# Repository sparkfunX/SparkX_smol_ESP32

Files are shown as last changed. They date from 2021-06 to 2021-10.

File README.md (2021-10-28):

# SparkX smôl ESP32

SparkX smôl ESP32 (SPX-18619) (https://www.sparkfun.com/products/18619)

[*SparkX smôl ESP32 (SPX-18619)*](https://www.sparkfun.com/products/18619)

The ESP32 in smôl format:
- ESP32 Processor
- WiFi antenna
- RTC crystal
- WS2812 RGB LED
- WS25Q128 128Mb Flash memory
- USB-C connector
- CP2102N USB-UART interface with RESET and BOOT control

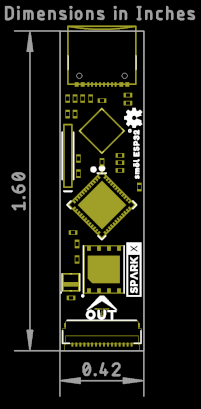
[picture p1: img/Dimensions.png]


## Repository Contents

- **/examples** - Example code for the Arduino IDE
- **/Documentation** - Datasheets etc.
- **/Hardware** - Eagle design files
- **LICENSE.md** contains the licence information

## Product Versions

- [SPX-18619](https://www.sparkfun.com/products/18619) - Original SparkX Release.

## License Information

This product is _**open source**_!

Please review the LICENSE.md file for license information.

If you have any questions or concerns on licensing, please contact technical support on our [SparkFun forums](https://forum.sparkfun.com/viewforum.php?f=123).

Distributed as-is; no warranty is given.

- Your friends at SparkFun.

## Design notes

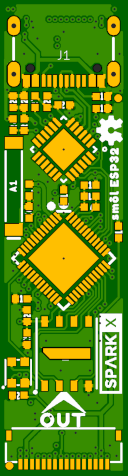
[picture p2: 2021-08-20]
img/Top.png

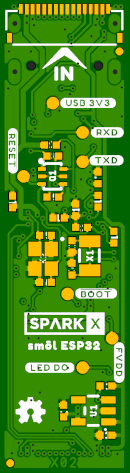
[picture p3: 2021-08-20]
img/Bottom.png

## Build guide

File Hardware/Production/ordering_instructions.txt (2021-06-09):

JLCPCB JLC7628 4-Layer 1.2mm Impedance Control
panel size, 193x96mm
PCB thickness, 1.2mm
number of layers, 4
soldermask color, Black
silkscreen color, White
oz copper, 1oz
finish, ENIG
stencils, top+bottom
pcs per panel, 32
min trace width, 0.1270mm / 0.0050in
min drill size, 0.2000mm / 0.0079in
filename to layer stackup 1/2/3/4: GTL, GL2, GL3, GBL

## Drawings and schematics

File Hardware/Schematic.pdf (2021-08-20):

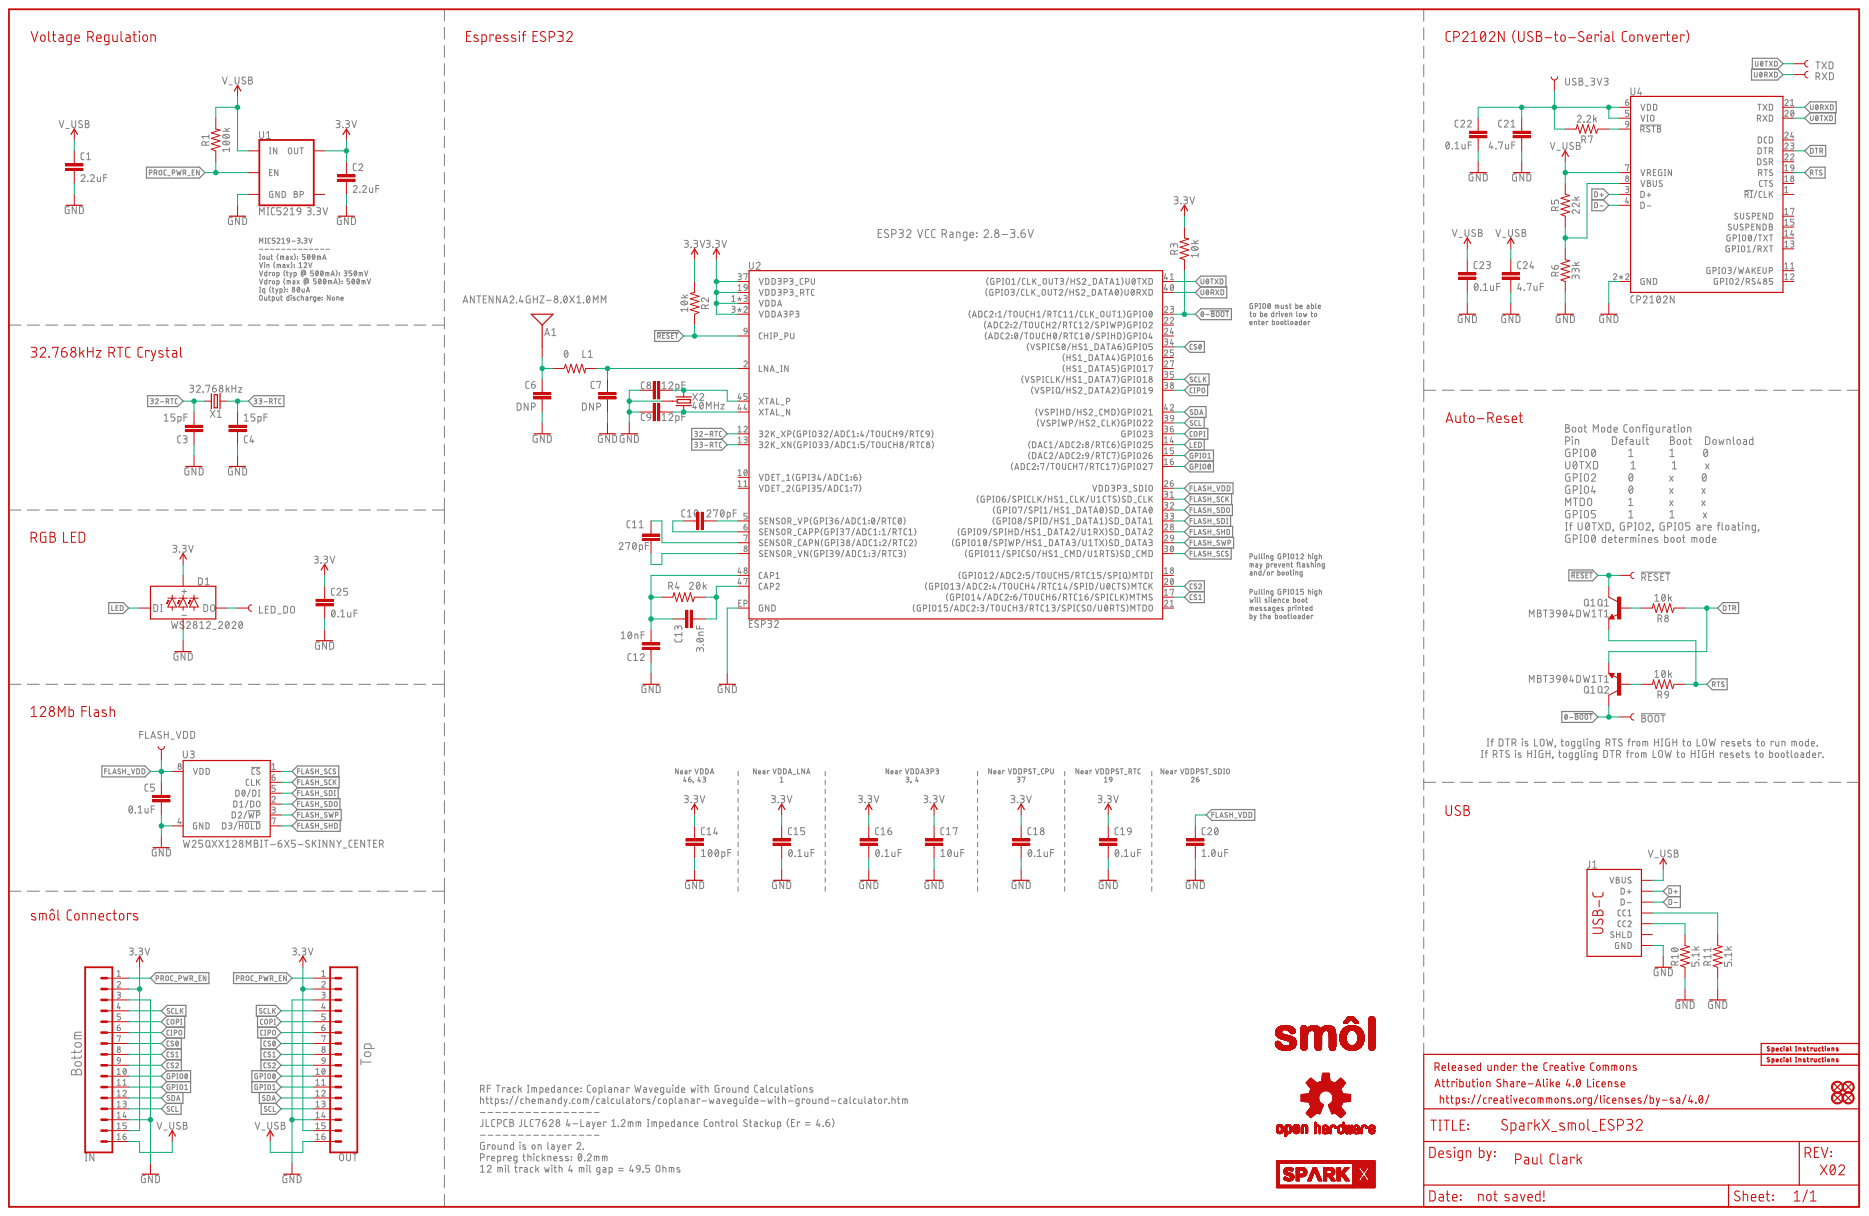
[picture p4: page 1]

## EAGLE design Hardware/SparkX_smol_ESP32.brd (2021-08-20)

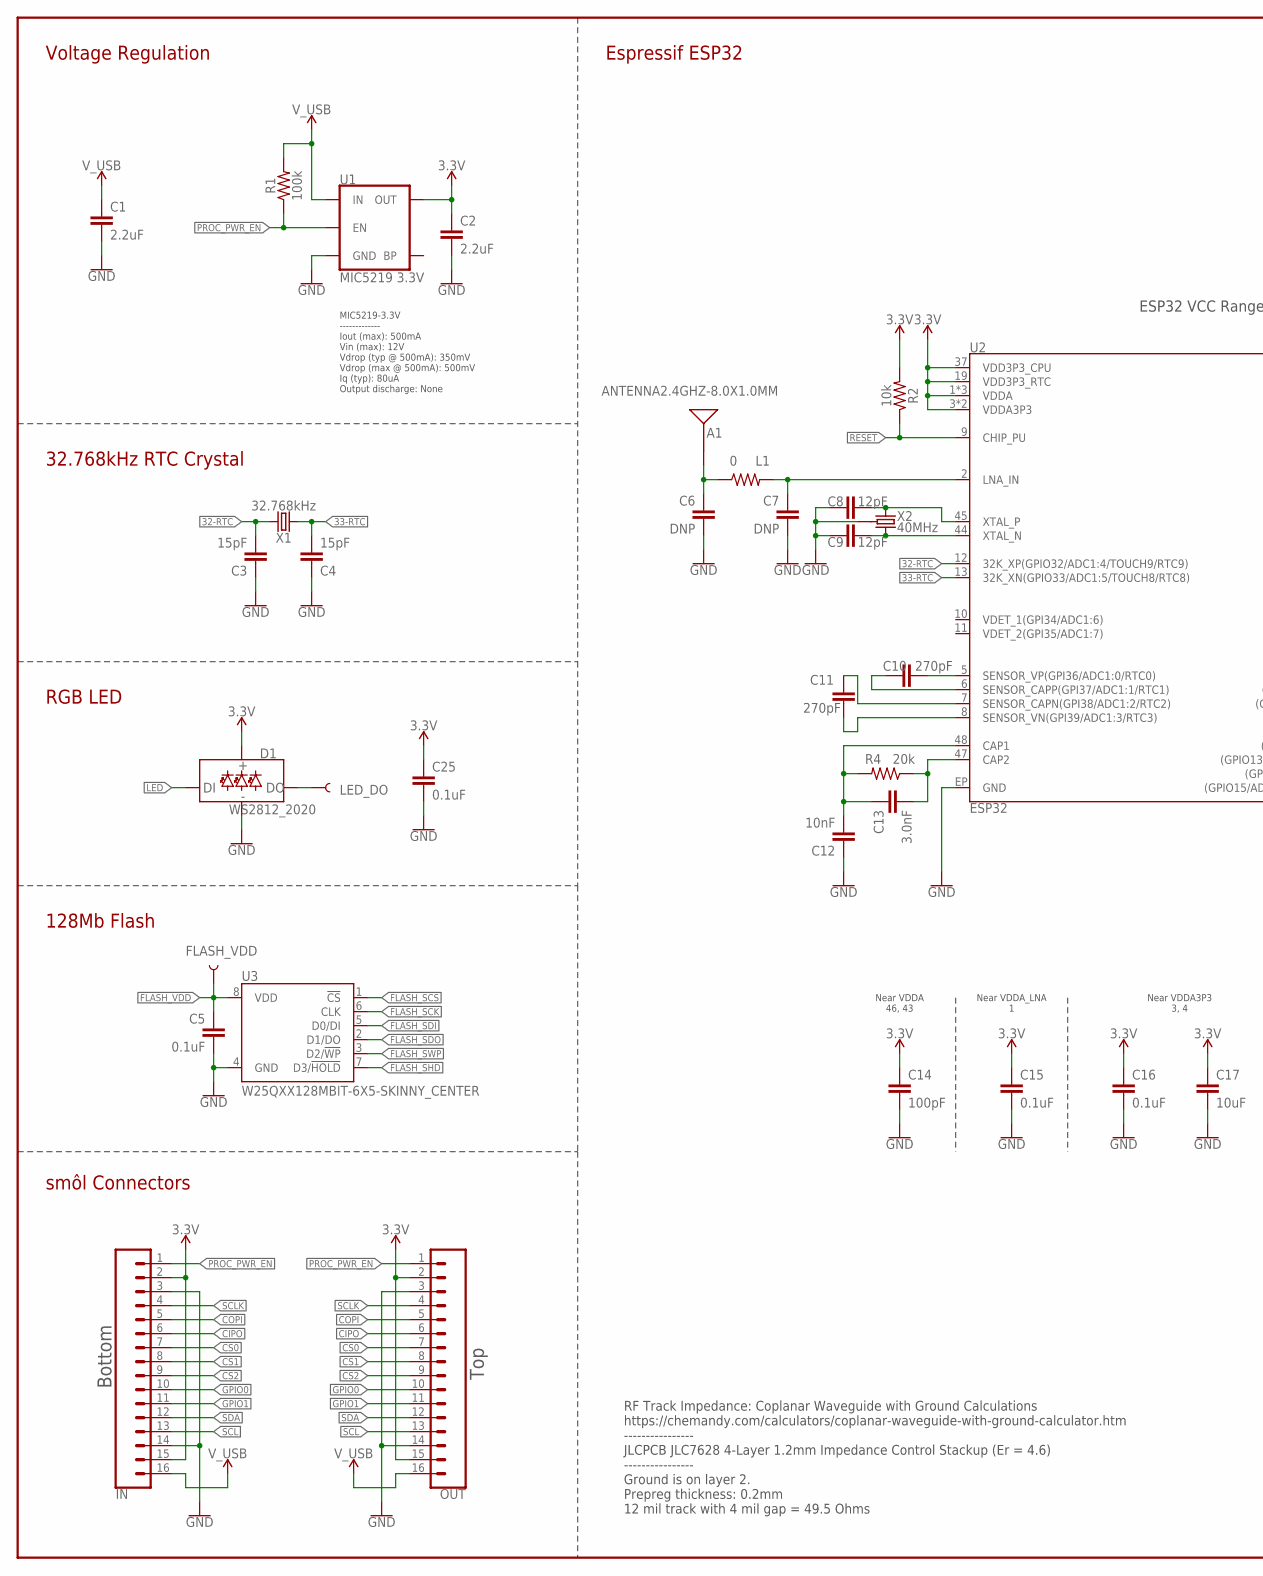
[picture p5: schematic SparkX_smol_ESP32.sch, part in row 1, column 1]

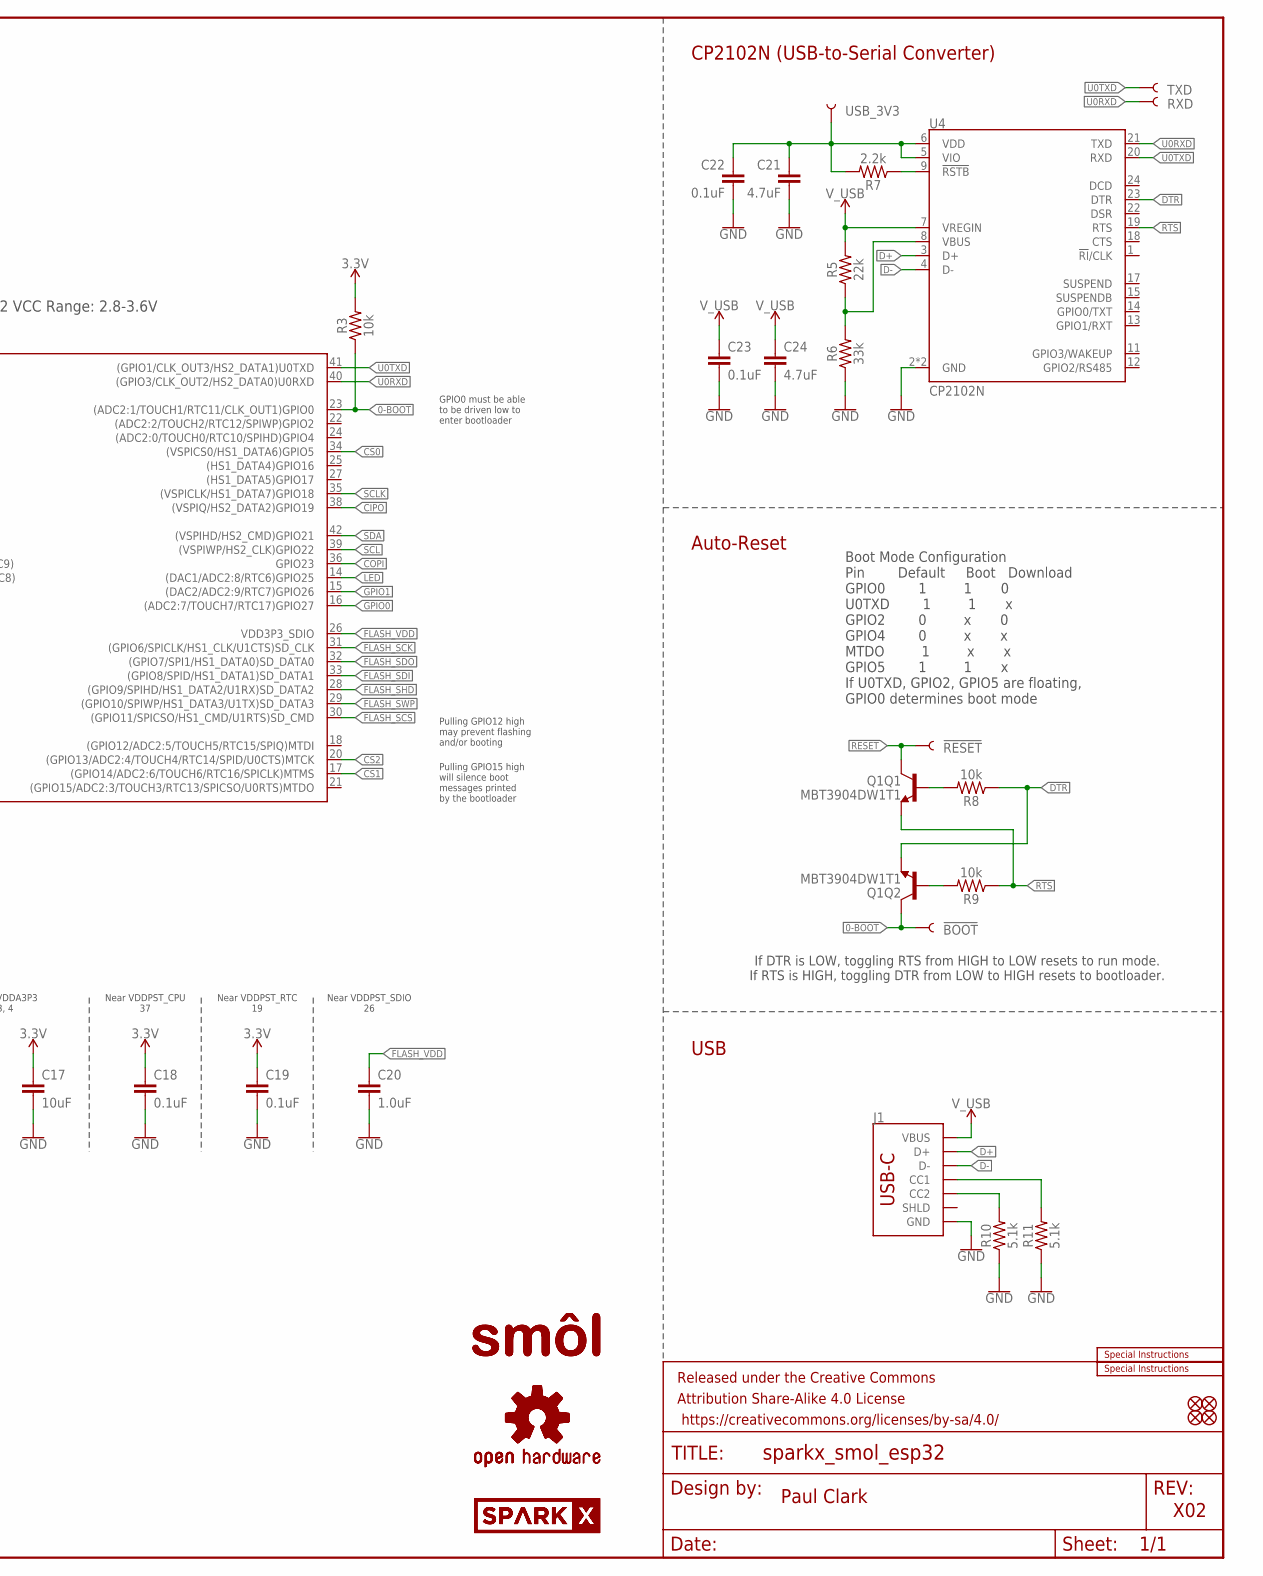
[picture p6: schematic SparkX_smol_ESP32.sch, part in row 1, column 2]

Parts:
!BOOT!: TEST-POINT3X4; PAD.03X.04
!RESET!: TEST-POINT3X4; PAD.03X.04
A1: ANTENNA2.4GHZ-8.0X1.0MM; ANT-2.4GHZ-8.0X1.0MM
C1, C2: 2.2uF; 0402-TIGHT
C3, C4: 15pF; 0402-TIGHT
C5, C15, C16, C18, C19, C22, C23, C25: 0.1uF; 0402-TIGHT
C6, C7: DNP; 0402-TIGHT_NO_CREAM
C8, C9: 12pF; 0402-TIGHT
C10, C11: 270pF; 0402-TIGHT
C12: 10nF; 0402-TIGHT
C13: 3.0nF; 0402-TIGHT
C14: 100pF; 0402-TIGHT
C17: 10uF; 0402-TIGHT
C20: 1.0uF; 0402-TIGHT
C21, C24: 4.7uF; 0402-TIGHT
D1: WS2812_2020; WS2812-2020
FD1, FD2, FD3, FD4: FIDUCIALUFIDUCIAL; FIDUCIAL-MICRO
FLASH_VDD: TEST-POINT3X4; PAD.03X.04
FRAME1: FRAME-LEDGER; CREATIVE_COMMONS
IN: CONN_16FPC_16_0.5MM; FPC_16_0.5MM
J1: USB_C_4-LAYER_PADS; USB-C-16P_4LAYER-PADS
L1: 0; 0402-TIGHT
LED_DO: TEST-POINT3X4; PAD.03X.04
LOGO1: SPECIAL_INSTRUCTIONS-ORDERING; ORDERING_INSTRUCTIONS
LOGO2, LOGO3: OSHW-LOGOMINI; OSHW-LOGO-MINI
LOGO4: SPECIAL_INSTRUCTIONS-PRODUCTION; PRODUCTION_INSTRUCTIONS
OUT: CONN_16FPC_16_0.5MM; FPC_16_0.5MM
Q1: MBT3904DW1T1; SC70-6
R1: 100k; 0402-TIGHT
R2, R3, R8, R9: 10k; 0402-TIGHT
R4: 20k; 0402-TIGHT
R5: 22k; 0402-TIGHT
R6: 33k; 0402-TIGHT
R7: 2.2k; 0402-TIGHT
R10, R11: 5.1k; 0402-TIGHT
RXD: TEST-POINT3X4; PAD.03X.04
TXD: TEST-POINT3X4; PAD.03X.04
U1: MIC5219 3.3V; SOT23-5
U2: ESP32; QFN48-0.4MM
U3: W25QXX128MBIT-6X5-SKINNY_CENTER; WSON-8-6X5-SKINNY_CENTERPAD
U4: CP2102N; QFN24
U$1, U$4: SPARKX-LOGO3; SPARKX-SMALL
U$14, U$15: SMOL_LOGOSMALL; SMOL_SMALL
USB_3V3: TEST-POINT3X4; PAD.03X.04
X1: 32.768kHz; CRYSTAL-SMD-3.2X1.5MM
X2: 40MHz; CRYSTAL-SMD-2X2.5MM

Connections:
0-!BOOT!: !BOOT!.1, Q1.6 (C), R3.1, U2.23 ((ADC2:1/TOUCH1/RTC11/CLK_OUT1)GPIO0)
1: C11.1, U2.7 (SENSOR_CAPN(GPI38/ADC1:2/RTC2))
3: C10.2, U2.5 (SENSOR_VP(GPI36/ADC1:0/RTC0))
3.3V: C2.1, C14.1, C15.1, C16.1, C17.1, C18.1, C19.1, C25.1, D1.VCC, IN.2, IN.15, OUT.2, OUT.15, R2.2, R3.2, U1.5 (OUT), U2.1 (VDDA), U2.3 (VDDA3P3), U2.4 (VDDA3P3), U2.19 (VDD3P3_RTC), U2.37 (VDD3P3_CPU), U2.43 (VDDA), U2.46 (VDDA)
6: C10.1, U2.6 (SENSOR_CAPP(GPI37/ADC1:1/RTC1))
32-RTC: C3.2, U2.12 (32K_XP(GPIO32/ADC1:4/TOUCH9/RTC9)), X1.P$1 (1)
33-RTC: C4.2, U2.13 (32K_XN(GPIO33/ADC1:5/TOUCH8/RTC8)), X1.P$2 (2)
!RESET: !RESET!.1, Q1.3 (C), R2.1, U2.9 (CHIP_PU)
CAP_10N1: C12.2, C13.1, R4.2, U2.48 (CAP1)
CIPO: IN.6, OUT.6, U2.38 ((VSPIQ/HS2_DATA2)GPIO19)
COPI: IN.5, OUT.5, U2.36 (GPIO23)
CS0: IN.7, OUT.7, U2.34 ((VSPICS0/HS1_DATA6)GPIO5)
CS1: IN.8, OUT.8, U2.17 ((GPIO14/ADC2:6/TOUCH6/RTC16/SPICLK)MTMS)
CS2: IN.9, OUT.9, U2.20 ((GPIO13/ADC2:4/TOUCH4/RTC14/SPID/U0CTS)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)
D+: J1.A6 (D+), J1.B6 (D+), U4.3 (D+)
D-: J1.A7 (D-), J1.B7 (D-), U4.4 (D-)
DTR: Q1.1 (E), R8.1, U4.23 (DTR)
FLASH_SCK: U2.31 ((GPIO6/SPICLK/HS1_CLK/U1CTS)SD_CLK), U3.6 (CLK)
FLASH_SCS: U2.30 ((GPIO11/SPICSO/HS1_CMD/U1RTS)SD_CMD), U3.1 (!CS!)
FLASH_SDI: U2.33 ((GPIO8/SPID/HS1_DATA1)SD_DATA1), U3.5 (D0/DI)
FLASH_SDO: U2.32 ((GPIO7/SPI1/HS1_DATA0)SD_DATA0), U3.2 (D1/DO)
FLASH_SHD: U2.28 ((GPIO9/SPIHD/HS1_DATA2/U1RX)SD_DATA2), U3.7 (D3/!HOLD!)
FLASH_SWP: U2.29 ((GPIO10/SPIWP/HS1_DATA3/U1TX)SD_DATA3), U3.3 (D2/!WP!)
FLASH_VDD: C5.1, C20.1, FLASH_VDD.1, U2.26 (VDD3P3_SDIO), U3.8 (VDD)
GND: C1.2, C2.2, C3.1, C4.1, C5.2, C6.2, C7.2, C8.1, C9.1, C12.1, C14.2, C15.2, C16.2, C17.2, C18.2, C19.2, C20.2, C21.2, C22.2, C23.2, C24.2, C25.2, D1.GND, IN.3, IN.14, J1.GND, J1.GND2 (GND), OUT.3, OUT.14, R6.1, R10.1, R11.1, U1.2 (GND), U2.EP (GND), U3.4 (GND), U4.2 (GND), U4.PAD (GND), X2.P2 (GND), X2.P4 (GND)
GPIO0: IN.10, OUT.10, U2.16 ((ADC2:7/TOUCH7/RTC17)GPIO27)
GPIO1: IN.11, OUT.11, U2.15 ((DAC2/ADC2:9/RTC7)GPIO26)
LED: D1.DI, U2.14 ((DAC1/ADC2:8/RTC6)GPIO25)
unnamed: J1.A5 (CC1), R11.2
unnamed: J1.B5 (CC2), R10.2
unnamed: C11.2, U2.8 (SENSOR_VN(GPI39/ADC1:3/RTC3))
unnamed: D1.DO, LED_DO.1
unnamed: Q1.5 (B), R8.2
unnamed: Q1.2 (B), R9.2
unnamed: C8.2, U2.45 (XTAL_P), X2.P1 (1)
unnamed: C9.2, U2.44 (XTAL_N), X2.P3 (2)
unnamed: C13.2, R4.1, U2.47 (CAP2)
unnamed: R5.1, R6.2, U4.8 (VBUS)
unnamed: R7.1, U4.9 (!RSTB)
unnamed: A1.FEED, C6.1, L1.1
unnamed: C7.1, L1.2, U2.2 (LNA_IN)
PROC_PWR_EN: IN.1, OUT.1, R1.1, U1.3 (EN)
RTS: Q1.4 (E), R9.1, U4.19 (RTS)
SCL: IN.13, OUT.13, U2.39 ((VSPIWP/HS2_CLK)GPIO22)
SCLK: IN.4, OUT.4, U2.35 ((VSPICLK/HS1_DATA7)GPIO18)
SDA: IN.12, OUT.12, U2.42 ((VSPIHD/HS2_CMD)GPIO21)
U0RXD: RXD.1, U2.40 ((GPIO3/CLK_OUT2/HS2_DATA0)U0RXD), U4.21 (TXD)
U0TXD: TXD.1, U2.41 ((GPIO1/CLK_OUT3/HS2_DATA1)U0TXD), U4.20 (RXD)
USB_3V3: C21.1, C22.1, R7.2, U4.5 (VIO), U4.6 (VDD), USB_3V3.1
V_USB: C1.1, C23.1, C24.1, IN.16, J1.VBUS1 (VBUS), J1.VBUS2 (VBUS), OUT.16, R1.2, R5.2, U1.1 (IN), U4.7 (VREGIN)

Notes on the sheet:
Paul Clark
X02
RF Track Impedance: Coplanar Waveguide with Ground Calculations https://chemandy.com/calculators/coplanar-waveguide-with-ground-calculator.htm ---------------- JLCPCB JLC7628 4-Layer 1.2mm Impedance Control Stackup (Er = 4.6) ---------------- Ground is on layer 2. Prepreg thickness: 0.2mm 12 mil tr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
smôl Connectors
Bottom
Top
Boot Mode Configuration Pin Default Boot Download GPIO0 1 1 0 U0TXD 1 1 x GPIO2 0 x 0 GPIO4 0 x x MTDO 1 x x GPIO5 1 1 x If U0TXD, GPIO2, GPIO5 are floating, GPIO0 determines boot mode
Auto-Reset
Near VDDA 46, 43
Near VDDA_LNA 1
Near VDDA3P3 3, 4
Near VDDPST_CPU 37
Near VDDPST_SDIO 26
Near VDDPST_RTC 19
Espressif ESP32
128Mb Flash
32.768kHz RTC Crystal
ESP32 VCC Range: 2.8-3.6V
If DTR is LOW, toggling RTS from HIGH to LOW resets to run mode. If RTS is HIGH, toggling DTR from LOW to HIGH resets to bootloader.
CP2102N (USB-to-Serial Converter)
GPIO0 must be able to be driven low to enter bootloader
Pulling GPIO12 high may prevent flashing and/or booting
Pulling GPIO15 high will silence boot messages printed by the bootloader
USB
MIC5219-3.3V ------------- Iout (max): 500mA Vin (max): 12V Vdrop (typ @ 500mA): 350mV Vdrop (max @ 500mA): 500mV Iq (typ): 80uA Output discharge: None
Voltage Regulation
RGB LED

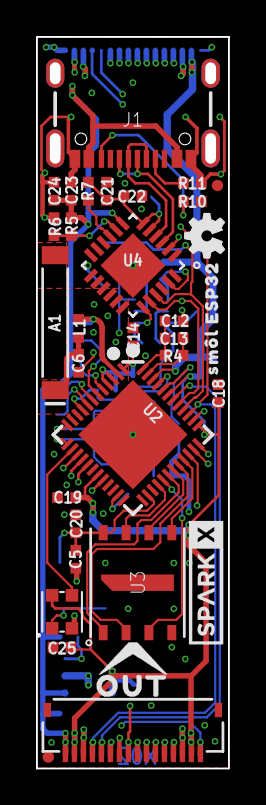
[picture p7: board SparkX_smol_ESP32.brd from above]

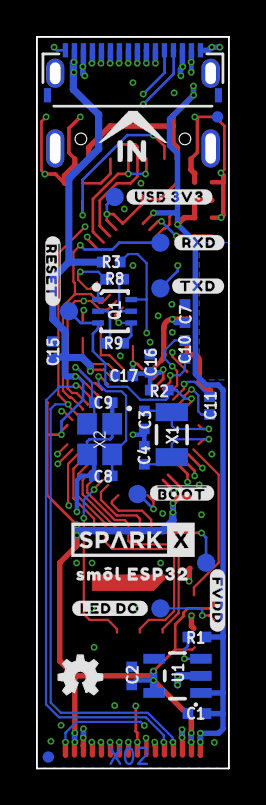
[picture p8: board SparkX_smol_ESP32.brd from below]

Board: 4 copper layers, 10.7 x 40.6 mm, 80 parts (43 on the bottom side), 50 nets.

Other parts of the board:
U$5, U$17: SM�L_ESP320
U$6: #TXD#0
U$7: ##BOOT##0
U$8: ##RESET##0
U$9: #USB_3V3#0
U$10: #FVDD#0
U$11: #LED_DO#0
U$12: IN0
U$13: OUT0
U$16: #RXD#0

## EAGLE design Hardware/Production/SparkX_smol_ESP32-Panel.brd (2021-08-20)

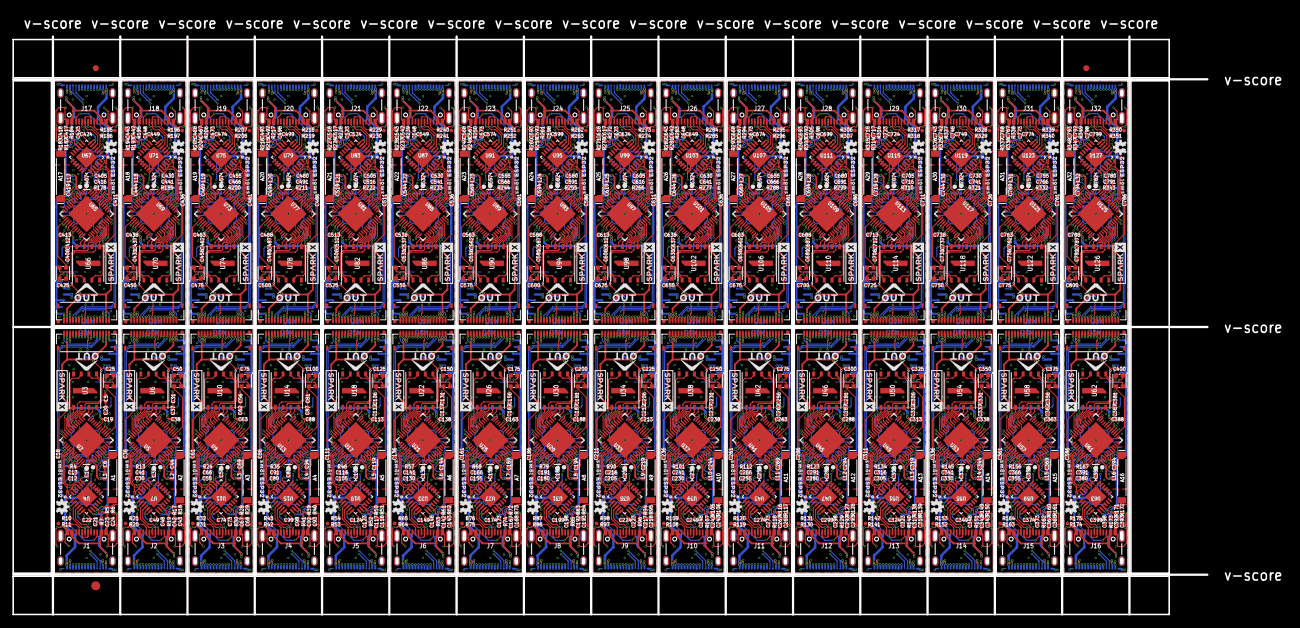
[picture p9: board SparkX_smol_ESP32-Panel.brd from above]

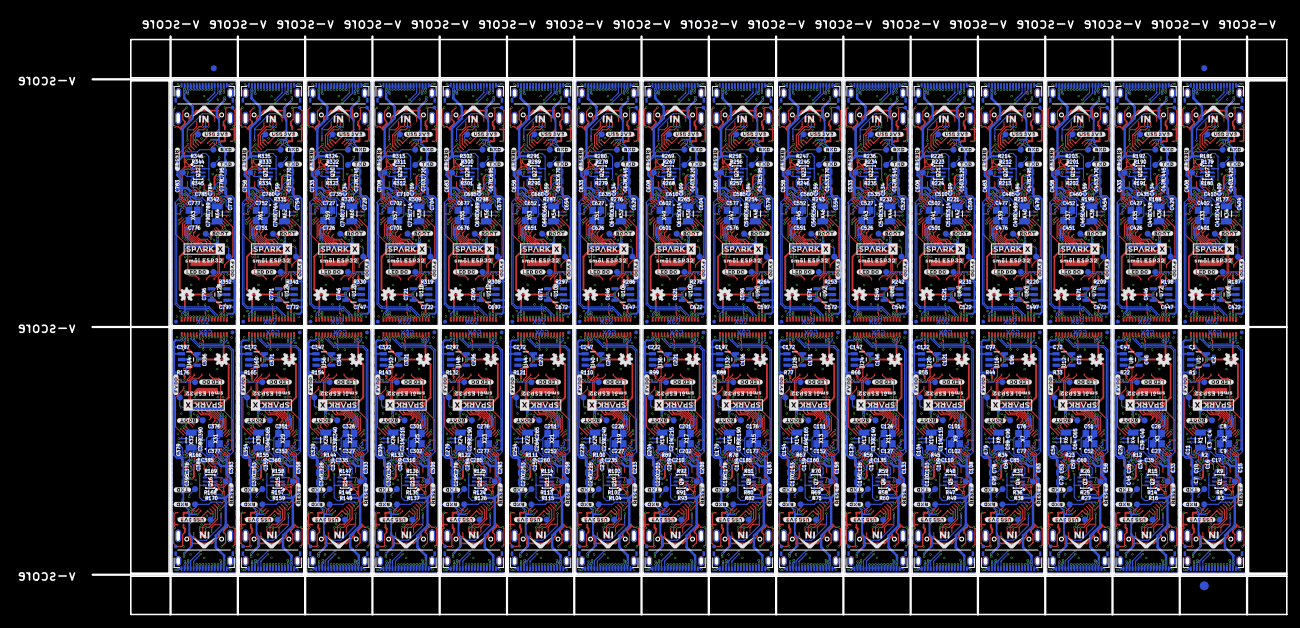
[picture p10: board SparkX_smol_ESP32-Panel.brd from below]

Board: 4 copper layers, 198.4 x 96.0 mm, 2470 parts (1379 on the bottom side), 1600 nets.

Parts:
!BOOT!, !BOOT!1, !BOOT!2, !BOOT!3, !BOOT!4, !BOOT!5, !BOOT!6, !BOOT!7, !BOOT!8, !BOOT!9, !BOOT!10, !BOOT!11, !BOOT!12, !BOOT!13, !BOOT!14, !BOOT!15, !BOOT!16, !BOOT!17, !BOOT!18, !BOOT!19, !BOOT!20, !BOOT!21, !BOOT!22, !BOOT!23, !BOOT!24, !BOOT!25, !BOOT!26, !BOOT!27, !BOOT!28, !BOOT!29, !BOOT!30, !BOOT!31: TEST-POINT3X4; PAD.03X.04
!RESET!, !RESET!1, !RESET!2, !RESET!3, !RESET!4, !RESET!5, !RESET!6, !RESET!7, !RESET!8, !RESET!9, !RESET!10, !RESET!11, !RESET!12, !RESET!13, !RESET!14, !RESET!15, !RESET!16, !RESET!17, !RESET!18, !RESET!19, !RESET!20, !RESET!21, !RESET!22, !RESET!23, !RESET!24, !RESET!25, !RESET!26, !RESET!27, !RESET!28, !RESET!29, !RESET!30, !RESET!31: TEST-POINT3X4; PAD.03X.04
A1, A2, A3, A4, A5, A6, A7, A8, A9, A10, A11, A12, A13, A14, A15, A16, A17, A18, A19, A20, A21, A22, A23, A24, A25, A26, A27, A28, A29, A30, A31, A32: ANTENNA2.4GHZ-8.0X1.0MM; ANT-2.4GHZ-8.0X1.0MM
C1, C2, C46, C47, C71, C72, C96, C97, C121, C122, C146, C147, C171, C172, C196, C197, C221, C222, C246, C247, C271, C272, C296, C297, C321, C322, C346, C347, C371, C372, C396, C397, C421, C422, C446, C447, C471, C472, C496, C497, C521, C522, C546, C547, C571, C572, C596, C597, C621, C622, C646, C647, C671, C672, C696, C697, C721, C722, C746, C747, C771, C772, C796, C797: 2.2uF; 0402-TIGHT
C3, C4, C39, C40, C64, C65, C89, C90, C114, C115, C139, C140, C164, C165, C189, C190, C214, C215, C239, C240, C264, C265, C289, C290, C314, C315, C339, C340, C364, C365, C389, C390, C414, C415, C439, C440, C464, C465, C489, C490, C514, C515, C539, C540, C564, C565, C589, C590, C614, C615, C639, C640, C664, C665, C689, C690, C714, C715, C739, C740, C764, C765, C789, C790: 15pF; 0402-TIGHT
C5, C15, C16, C18, C19, C22, C23, C25, C31, C33, C34, C36, C38, C42, C49, C50, C56, C58, C59, C61, C63, C67, C74, C75, C81, C83, C84, C86, C88, C92, C99, C100, C106, C108, C109, C111, C113, C117, C124, C125, C131, C133, C134, C136, C138, C142, C149, C150, C156, C158, C159, C161, C163, C167, C174, C175, C181, C183, C184, C186, C188, C192, C199, C200, C206, C208, C209, C211, C213, C217, C224, C225, C231, C233, C234, C236, C238, C242, C249, C250, C256, C258, C259, C261, C263, C267, C274, C275, C281, C283, C284, C286, C288, C292, C299, C300, C306, C308, C309, C311, C313, C317, C324, C325, C331, C333, C334, C336, C338, C342, C349, C350, C356, C358, C359, C361, C363, C367, C374, C375, C381, C383, C384, C386, C388, C392, C399, C400, C406, C408, C409, C411, C413, C417, C424, C425, C431, C433, C434, C436, C438, C442, C449, C450, C456, C458, C459, C461, C463, C467, C474, C475, C481, C483, C484, C486, C488, C492, C499, C500, C506, C508, C509, C511, C513, C517, C524, C525, C531, C533, C534, C536, C538, C542, C549, C550, C556, C558, C559, C561, C563, C567, C574, C575, C581, C583, C584, C586, C588, C592, C599, C600, C606, C608, C609, C611, C613, C617, C624, C625, C631, C633, C634, C636, C638, C642, C649, C650, C656, C658, C659, C661, C663, C667, C674, C675, C681, C683, C684, C686, C688, C692, C699, C700, C706, C708, C709, C711, C713, C717, C724, C725, C731, C733, C734, C736, C738, C742, C749, C750, C756, C758, C759, C761, C763, C767, C774, C775, C781, C783, C784, C786, C788, C792, C799, C800: 0.1uF; 0402-TIGHT
C6, C7, C44, C45, C69, C70, C94, C95, C119, C120, C144, C145, C169, C170, C194, C195, C219, C220, C244, C245, C269, C270, C294, C295, C319, C320, C344, C345, C369, C370, C394, C395, C419, C420, C444, C445, C469, C470, C494, C495, C519, C520, C544, C545, C569, C570, C594, C595, C619, C620, C644, C645, C669, C670, C694, C695, C719, C720, C744, C745, C769, C770, C794, C795: DNP; 0402-TIGHT_NO_CREAM
C8, C9, C26, C27, C51, C52, C76, C77, C101, C102, C126, C127, C151, C152, C176, C177, C201, C202, C226, C227, C251, C252, C276, C277, C301, C302, C326, C327, C351, C352, C376, C377, C401, C402, C426, C427, C451, C452, C476, C477, C501, C502, C526, C527, C551, C552, C576, C577, C601, C602, C626, C627, C651, C652, C676, C677, C701, C702, C726, C727, C751, C752, C776, C777: 12pF; 0402-TIGHT
C10, C11, C28, C29, C53, C54, C78, C79, C103, C104, C128, C129, C153, C154, C178, C179, C203, C204, C228, C229, C253, C254, C278, C279, C303, C304, C328, C329, C353, C354, C378, C379, C403, C404, C428, C429, C453, C454, C478, C479, C503, C504, C528, C529, C553, C554, C578, C579, C603, C604, C628, C629, C653, C654, C678, C679, C703, C704, C728, C729, C753, C754, C778, C779: 270pF; 0402-TIGHT
C12, C30, C55, C80, C105, C130, C155, C180, C205, C230, C255, C280, C305, C330, C355, C380, C405, C430, C455, C480, C505, C530, C555, C580, C605, C630, C655, C680, C705, C730, C755, C780: 10nF; 0402-TIGHT
C13, C41, C66, C91, C116, C141, C166, C191, C216, C241, C266, C291, C316, C341, C366, C391, C416, C441, C466, C491, C516, C541, C566, C591, C616, C641, C666, C691, C716, C741, C766, C791: 3.0nF; 0402-TIGHT
C14, C32, C57, C82, C107, C132, C157, C182, C207, C232, C257, C282, C307, C332, C357, C382, C407, C432, C457, C482, C507, C532, C557, C582, C607, C632, C657, C682, C707, C732, C757, C782: 100pF; 0402-TIGHT
C17, C35, C60, C85, C110, C135, C160, C185, C210, C235, C260, C285, C310, C335, C360, C385, C410, C435, C460, C485, C510, C535, C560, C585, C610, C635, C660, C685, C710, C735, C760, C785: 10uF; 0402-TIGHT
C20, C37, C62, C87, C112, C137, C162, C187, C212, C237, C262, C287, C312, C337, C362, C387, C412, C437, C462, C487, C512, C537, C562, C587, C612, C637, C662, C687, C712, C737, C762, C787: 1.0uF; 0402-TIGHT
C21, C24, C43, C48, C68, C73, C93, C98, C118, C123, C143, C148, C168, C173, C193, C198, C218, C223, C243, C248, C268, C273, C293, C298, C318, C323, C343, C348, C368, C373, C393, C398, C418, C423, C443, C448, C468, C473, C493, C498, C518, C523, C543, C548, C568, C573, C593, C598, C618, C623, C643, C648, C668, C673, C693, C698, C718, C723, C743, C748, C768, C773, C793, C798: 4.7uF; 0402-TIGHT
D1, D2, D3, D4, D5, D6, D7, D8, D9, D10, D11, D12, D13, D14, D15, D16, D17, D18, D19, D20, D21, D22, D23, D24, D25, D26, D27, D28, D29, D30, D31, D32: WS2812_2020; WS2812-2020
E$1, E$2, E$3, E$4: FIDUCIAL-1X2
E$5, E$6: FIDUCIAL-1.5X3
FD1, FD2, FD3, FD4, FD5, FD6, FD7, FD8, FD9, FD10, FD11, FD12, FD13, FD14, FD15, FD16, FD17, FD18, FD19, FD20, FD21, FD22, FD23, FD24, FD25, FD26, FD27, FD28, FD29, FD30, FD31, FD32, FD33, FD34, FD35, FD36, FD37, FD38, FD39, FD40, FD41, FD42, FD43, FD44, FD45, FD46, FD47, FD48, FD49, FD50, FD51, FD52, FD53, FD54, FD55, FD56, FD57, FD58, FD59, FD60, FD61, FD62, FD63, FD64, FD65, FD66, FD67, FD68, FD69, FD70, FD71, FD72, FD73, FD74, FD75, FD76, FD77, FD78, FD79, FD80, FD81, FD82, FD83, FD84, FD85, FD86, FD87, FD88, FD89, FD90, FD91, FD92, FD93, FD94, FD95, FD96, FD97, FD98, FD99, FD100, FD101, FD102, FD103, FD104, FD105, FD106, FD107, FD108, FD109, FD110, FD111, FD112, FD113, FD114, FD115, FD116, FD117, FD118, FD119, FD120, FD121, FD122, FD123, FD124, FD125, FD126, FD127, FD128: FIDUCIALUFIDUCIAL; FIDUCIAL-MICRO
FLASH_VDD, FLASH_VDD1, FLASH_VDD2, FLASH_VDD3, FLASH_VDD4, FLASH_VDD5, FLASH_VDD6, FLASH_VDD7, FLASH_VDD8, FLASH_VDD9, FLASH_VDD10, FLASH_VDD11, FLASH_VDD12, FLASH_VDD13, FLASH_VDD14, FLASH_VDD15, FLASH_VDD16, FLASH_VDD17, FLASH_VDD18, FLASH_VDD19, FLASH_VDD20, FLASH_VDD21, FLASH_VDD22, FLASH_VDD23, FLASH_VDD24, FLASH_VDD25, FLASH_VDD26, FLASH_VDD27, FLASH_VDD28, FLASH_VDD29, FLASH_VDD30, FLASH_VDD31: TEST-POINT3X4; PAD.03X.04
IN, IN1, IN2, IN3, IN4, IN5, IN6, IN7, IN8, IN9, IN10, IN11, IN12, IN13, IN14, IN15, IN16, IN17, IN18, IN19, IN20, IN21, IN22, IN23, IN24, IN25, IN26, IN27, IN28, IN29, IN30, IN31: FPC_16_0.5MM
J1, J2, J3, J4, J5, J6, J7, J8, J9, J10, J11, J12, J13, J14, J15, J16, J17, J18, J19, J20, J21, J22, J23, J24, J25, J26, J27, J28, J29, J30, J31, J32: USB-C-16P_4LAYER-PADS
L1, L2, L3, L4, L5, L6, L7, L8, L9, L10, L11, L12, L13, L14, L15, L16, L17, L18, L19, L20, L21, L22, L23, L24, L25, L26, L27, L28, L29, L30, L31, L32: 0; 0402-TIGHT
LED_DO, LED_DO1, LED_DO2, LED_DO3, LED_DO4, LED_DO5, LED_DO6, LED_DO7, LED_DO8, LED_DO9, LED_DO10, LED_DO11, LED_DO12, LED_DO13, LED_DO14, LED_DO15, LED_DO16, LED_DO17, LED_DO18, LED_DO19, LED_DO20, LED_DO21, LED_DO22, LED_DO23, LED_DO24, LED_DO25, LED_DO26, LED_DO27, LED_DO28, LED_DO29, LED_DO30, LED_DO31: TEST-POINT3X4; PAD.03X.04
LOGO1, LOGO2, LOGO3, LOGO4, LOGO5, LOGO6, LOGO7, LOGO8, LOGO9, LOGO10, LOGO11, LOGO12, LOGO13, LOGO14, LOGO15, LOGO16, LOGO17, LOGO18, LOGO19, LOGO20, LOGO21, LOGO22, LOGO23, LOGO24, LOGO25, LOGO26, LOGO27, LOGO28, LOGO29, LOGO30, LOGO31, LOGO32, LOGO33, LOGO34, LOGO35, LOGO36, LOGO37, LOGO38, LOGO39, LOGO40, LOGO41, LOGO42, LOGO43, LOGO44, LOGO45, LOGO46, LOGO47, LOGO48, LOGO49, LOGO50, LOGO51, LOGO52, LOGO53, LOGO54, LOGO55, LOGO56, LOGO57, LOGO58, LOGO59, LOGO60, LOGO61, LOGO62, LOGO63, LOGO64: OSHW-LOGOMINI; OSHW-LOGO-MINI
OUT, OUT1, OUT2, OUT3, OUT4, OUT5, OUT6, OUT7, OUT8, OUT9, OUT10, OUT11, OUT12, OUT13, OUT14, OUT15, OUT16, OUT17, OUT18, OUT19, OUT20, OUT21, OUT22, OUT23, OUT24, OUT25, OUT26, OUT27, OUT28, OUT29, OUT30, OUT31: FPC_16_0.5MM
Q1, Q2, Q3, Q4, Q5, Q6, Q7, Q8, Q9, Q10, Q11, Q12, Q13, Q14, Q15, Q16, Q17, Q18, Q19, Q20, Q21, Q22, Q23, Q24, Q25, Q26, Q27, Q28, Q29, Q30, Q31, Q32: MBT3904DW1T1; SC70-6
R1, R22, R33, R44, R55, R66, R77, R88, R99, R110, R121, R132, R143, R154, R165, R176, R187, R198, R209, R220, R231, R242, R253, R264, R275, R286, R297, R308, R319, R330, R341, R352: 100k; 0402-TIGHT
R2, R3, R8, R9, R12, R14, R15, R16, R23, R25, R26, R27, R34, R36, R37, R38, R45, R47, R48, R49, R56, R58, R59, R60, R67, R69, R70, R71, R78, R80, R81, R82, R89, R91, R92, R93, R100, R102, R103, R104, R111, R113, R114, R115, R122, R124, R125, R126, R133, R135, R136, R137, R144, R146, R147, R148, R155, R157, R158, R159, R166, R168, R169, R170, R177, R179, R180, R181, R188, R190, R191, R192, R199, R201, R202, R203, R210, R212, R213, R214, R221, R223, R224, R225, R232, R234, R235, R236, R243, R245, R246, R247, R254, R256, R257, R258, R265, R267, R268, R269, R276, R278, R279, R280, R287, R289, R290, R291, R298, R300, R301, R302, R309, R311, R312, R313, R320, R322, R323, R324, R331, R333, R334, R335, R342, R344, R345, R346: 10k; 0402-TIGHT
R4, R13, R24, R35, R46, R57, R68, R79, R90, R101, R112, R123, R134, R145, R156, R167, R178, R189, R200, R211, R222, R233, R244, R255, R266, R277, R288, R299, R310, R321, R332, R343: 20k; 0402-TIGHT
R5, R17, R28, R39, R50, R61, R72, R83, R94, R105, R116, R127, R138, R149, R160, R171, R182, R193, R204, R215, R226, R237, R248, R259, R270, R281, R292, R303, R314, R325, R336, R347: 22k; 0402-TIGHT
R6, R18, R29, R40, R51, R62, R73, R84, R95, R106, R117, R128, R139, R150, R161, R172, R183, R194, R205, R216, R227, R238, R249, R260, R271, R282, R293, R304, R315, R326, R337, R348: 33k; 0402-TIGHT
R7, R19, R30, R41, R52, R63, R74, R85, R96, R107, R118, R129, R140, R151, R162, R173, R184, R195, R206, R217, R228, R239, R250, R261, R272, R283, R294, R305, R316, R327, R338, R349: 2.2k; 0402-TIGHT
R10, R11, R20, R21, R31, R32, R42, R43, R53, R54, R64, R65, R75, R76, R86, R87, R97, R98, R108, R109, R119, R120, R130, R131, R141, R142, R152, R153, R163, R164, R174, R175, R185, R186, R196, R197, R207, R208, R218, R219, R229, R230, R240, R241, R251, R252, R262, R263, R273, R274, R284, R285, R295, R296, R306, R307, R317, R318, R328, R329, R339, R340, R350, R351: 5.1k; 0402-TIGHT
RXD, RXD1, RXD2, RXD3, RXD4, RXD5, RXD6, RXD7, RXD8, RXD9, RXD10, RXD11, RXD12, RXD13, RXD14, RXD15, RXD16, RXD17, RXD18, RXD19, RXD20, RXD21, RXD22, RXD23, RXD24, RXD25, RXD26, RXD27, RXD28, RXD29, RXD30, RXD31: TEST-POINT3X4; PAD.03X.04
TXD, TXD1, TXD2, TXD3, TXD4, TXD5, TXD6, TXD7, TXD8, TXD9, TXD10, TXD11, TXD12, TXD13, TXD14, TXD15, TXD16, TXD17, TXD18, TXD19, TXD20, TXD21, TXD22, TXD23, TXD24, TXD25, TXD26, TXD27, TXD28, TXD29, TXD30, TXD31: TEST-POINT3X4; PAD.03X.04
U1, U8, U12, U16, U20, U24, U28, U32, U36, U40, U44, U48, U52, U56, U60, U64, U68, U72, U76, U80, U84, U88, U92, U96, U100, U104, U108, U112, U116, U120, U124, U128: MIC5219 3.3V; SOT23-5
U2, U5, U9, U13, U17, U21, U25, U29, U33, U37, U41, U45, U49, U53, U57, U61, U65, U69, U73, U77, U81, U85, U89, U93, U97, U101, U105, U109, U113, U117, U121, U125: ESP32; QFN48-0.4MM
U3, U6, U10, U14, U18, U22, U26, U30, U34, U38, U42, U46, U50, U54, U58, U62, U66, U70, U74, U78, U82, U86, U90, U94, U98, U102, U106, U110, U114, U118, U122, U126: W25QXX128MBIT-6X5-SKINNY_CENTER; WSON-8-6X5-SKINNY_CENTERPAD
U4, U7, U11, U15, U19, U23, U27, U31, U35, U39, U43, U47, U51, U55, U59, U63, U67, U71, U75, U79, U83, U87, U91, U95, U99, U103, U107, U111, U115, U119, U123, U127: CP2102N; QFN24
U$1, U$2, U$3, U$4, U$31, U$32, U$46, U$47, U$61, U$62, U$76, U$77, U$91, U$92, U$106, U$107, U$121, U$122, U$136, U$137, U$151, U$152, U$166, U$167, U$181, U$182, U$196, U$197, U$211, U$212, U$226, U$227, U$241, U$242, U$256, U$257, U$271, U$272, U$286, U$287, U$301, U$302, U$316, U$317, U$331, U$332, U$346, U$347, U$361, U$362, U$376, U$377, U$391, U$392, U$406, U$407, U$421, U$422, U$436, U$437, U$451, U$452, U$466, U$467: SPARKX-LOGO3; SPARKX-SMALL
U$5, U$17, U$29, U$30, U$44, U$45, U$59, U$60, U$74, U$75, U$89, U$90, U$104, U$105, U$119, U$120, U$134, U$135, U$149, U$150, U$164, U$165, U$179, U$180, U$194, U$195, U$209, U$210, U$224, U$225, U$239, U$240, U$254, U$255, U$269, U$270, U$284, U$285, U$299, U$300, U$314, U$315, U$329, U$330, U$344, U$345, U$359, U$360, U$374, U$375, U$389, U$390, U$404, U$405, U$419, U$420, U$434, U$435, U$449, U$450, U$464, U$465, U$479, U$480: SM�L_ESP320
U$6, U$28, U$43, U$58, U$73, U$88, U$103, U$118, U$133, U$148, U$163, U$178, U$193, U$208, U$223, U$238, U$253, U$268, U$283, U$298, U$313, U$328, U$343, U$358, U$373, U$388, U$403, U$418, U$433, U$448, U$463, U$478: #TXD#0
U$7, U$18, U$33, U$48, U$63, U$78, U$93, U$108, U$123, U$138, U$153, U$168, U$183, U$198, U$213, U$228, U$243, U$258, U$273, U$288, U$303, U$318, U$333, U$348, U$363, U$378, U$393, U$408, U$423, U$438, U$453, U$468: ##BOOT##0
U$8, U$19, U$34, U$49, U$64, U$79, U$94, U$109, U$124, U$139, U$154, U$169, U$184, U$199, U$214, U$229, U$244, U$259, U$274, U$289, U$304, U$319, U$334, U$349, U$364, U$379, U$394, U$409, U$424, U$439, U$454, U$469: ##RESET##0
U$9, U$20, U$35, U$50, U$65, U$80, U$95, U$110, U$125, U$140, U$155, U$170, U$185, U$200, U$215, U$230, U$245, U$260, U$275, U$290, U$305, U$320, U$335, U$350, U$365, U$380, U$395, U$410, U$425, U$440, U$455, U$470: #USB_3V3#0
U$10, U$21, U$36, U$51, U$66, U$81, U$96, U$111, U$126, U$141, U$156, U$171, U$186, U$201, U$216, U$231, U$246, U$261, U$276, U$291, U$306, U$321, U$336, U$351, U$366, U$381, U$396, U$411, U$426, U$441, U$456, U$471: #FVDD#0
U$11, U$22, U$37, U$52, U$67, U$82, U$97, U$112, U$127, U$142, U$157, U$172, U$187, U$202, U$217, U$232, U$247, U$262, U$277, U$292, U$307, U$322, U$337, U$352, U$367, U$382, U$397, U$412, U$427, U$442, U$457, U$472: #LED_DO#0
U$12, U$26, U$41, U$56, U$71, U$86, U$101, U$116, U$131, U$146, U$161, U$176, U$191, U$206, U$221, U$236, U$251, U$266, U$281, U$296, U$311, U$326, U$341, U$356, U$371, U$386, U$401, U$416, U$431, U$446, U$461, U$476: IN0
U$13, U$25, U$40, U$55, U$70, U$85, U$100, U$115, U$130, U$145, U$160, U$175, U$190, U$205, U$220, U$235, U$250, U$265, U$280, U$295, U$310, U$325, U$340, U$355, U$370, U$385, U$400, U$415, U$430, U$445, U$460, U$475: OUT0
U$14, U$15, U$23, U$24, U$38, U$39, U$53, U$54, U$68, U$69, U$83, U$84, U$98, U$99, U$113, U$114, U$128, U$129, U$143, U$144, U$158, U$159, U$173, U$174, U$188, U$189, U$203, U$204, U$218, U$219, U$233, U$234, U$248, U$249, U$263, U$264, U$278, U$279, U$293, U$294, U$308, U$309, U$323, U$324, U$338, U$339, U$353, U$354, U$368, U$369, U$383, U$384, U$398, U$399, U$413, U$414, U$428, U$429, U$443, U$444, U$458, U$459, U$473, U$474: SMOL_LOGOSMALL; SMOL_SMALL
U$16, U$27, U$42, U$57, U$72, U$87, U$102, U$117, U$132, U$147, U$162, U$177, U$192, U$207, U$222, U$237, U$252, U$267, U$282, U$297, U$312, U$327, U$342, U$357, U$372, U$387, U$402, U$417, U$432, U$447, U$462, U$477: #RXD#0
USB_3V1, USB_3V2, USB_3V3, USB_3V4, USB_3V5, USB_3V6, USB_3V7, USB_3V8, USB_3V9, USB_3V10, USB_3V11, USB_3V12, USB_3V13, USB_3V14, USB_3V15, USB_3V16, USB_3V17, USB_3V18, USB_3V19, USB_3V20, USB_3V21, USB_3V22, USB_3V23, USB_3V24, USB_3V25, USB_3V26, USB_3V27, USB_3V28, USB_3V29, USB_3V30, USB_3V31, USB_3V32: TEST-POINT3X4; PAD.03X.04
X1, X4, X6, X8, X10, X12, X14, X16, X18, X20, X22, X24, X26, X28, X30, X32, X34, X36, X38, X40, X42, X44, X46, X48, X50, X52, X54, X56, X58, X60, X62, X64: 32.768kHz; CRYSTAL-SMD-3.2X1.5MM
X2, X3, X5, X7, X9, X11, X13, X15, X17, X19, X21, X23, X25, X27, X29, X31, X33, X35, X37, X39, X41, X43, X45, X47, X49, X51, X53, X55, X57, X59, X61, X63: 40MHz; CRYSTAL-SMD-2X2.5MM

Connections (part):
0-!BOOT!: !BOOT!.1, Q1.6, R3.1, U2.23
0-!BOOT!1: !BOOT!1.1, Q2.6, R16.1, U5.23
0-!BOOT!2: !BOOT!2.1, Q3.6, R27.1, U9.23
0-!BOOT!3: !BOOT!3.1, Q4.6, R38.1, U13.23
0-!BOOT!4: !BOOT!4.1, Q5.6, R49.1, U17.23
0-!BOOT!5: !BOOT!5.1, Q6.6, R60.1, U21.23
0-!BOOT!6: !BOOT!6.1, Q7.6, R71.1, U25.23
0-!BOOT!7: !BOOT!7.1, Q8.6, R82.1, U29.23
0-!BOOT!8: !BOOT!8.1, Q9.6, R93.1, U33.23
0-!BOOT!9: !BOOT!9.1, Q10.6, R104.1, U37.23
0-!BOOT!10: !BOOT!10.1, Q11.6, R115.1, U41.23
0-!BOOT!11: !BOOT!11.1, Q12.6, R126.1, U45.23
0-!BOOT!12: !BOOT!12.1, Q13.6, R137.1, U49.23
0-!BOOT!13: !BOOT!13.1, Q14.6, R148.1, U53.23
0-!BOOT!14: !BOOT!14.1, Q15.6, R159.1, U57.23
0-!BOOT!15: !BOOT!15.1, Q16.6, R170.1, U61.23
0-!BOOT!16: !BOOT!16.1, Q17.6, R181.1, U65.23
0-!BOOT!17: !BOOT!17.1, Q18.6, R192.1, U69.23
0-!BOOT!18: !BOOT!18.1, Q19.6, R203.1, U73.23
0-!BOOT!19: !BOOT!19.1, Q20.6, R214.1, U77.23
0-!BOOT!20: !BOOT!20.1, Q21.6, R225.1, U81.23
0-!BOOT!21: !BOOT!21.1, Q22.6, R236.1, U85.23
0-!BOOT!22: !BOOT!22.1, Q23.6, R247.1, U89.23
0-!BOOT!23: !BOOT!23.1, Q24.6, R258.1, U93.23
0-!BOOT!24: !BOOT!24.1, Q25.6, R269.1, U97.23
0-!BOOT!25: !BOOT!25.1, Q26.6, R280.1, U101.23
0-!BOOT!26: !BOOT!26.1, Q27.6, R291.1, U105.23
0-!BOOT!27: !BOOT!27.1, Q28.6, R302.1, U109.23
0-!BOOT!28: !BOOT!28.1, Q29.6, R313.1, U113.23
0-!BOOT!29: !BOOT!29.1, Q30.6, R324.1, U117.23
0-!BOOT!30: !BOOT!30.1, Q31.6, R335.1, U121.23
0-!BOOT!31: !BOOT!31.1, Q32.6, R346.1, U125.23
1: C11.1, U2.7
2: C29.1, U5.7
3: C10.2, U2.5
3.3V: C2.1, C14.1, C15.1, C16.1, C17.1, C18.1, C19.1, C25.1, D1.VCC, IN.2, IN.15, OUT.2, OUT.15, R2.2, R3.2, U1.5, U2.1, U2.3, U2.4, U2.19, U2.37, U2.43, U2.46
3.3V1: C32.1, C33.1, C34.1, C35.1, C36.1, C38.1, C46.1, C50.1, D2.VCC, IN1.2, IN1.15, OUT1.2, OUT1.15, R12.2, R16.2, U5.1, U5.3, U5.4, U5.19, U5.37, U5.43, U5.46, U8.5
3.3V2: C57.1, C58.1, C59.1, C60.1, C61.1, C63.1, C71.1, C75.1, D3.VCC, IN2.2, IN2.15, OUT2.2, OUT2.15, R23.2, R27.2, U9.1, U9.3, U9.4, U9.19, U9.37, U9.43, U9.46, U12.5
3.3V3: C82.1, C83.1, C84.1, C85.1, C86.1, C88.1, C96.1, C100.1, D4.VCC, IN3.2, IN3.15, OUT3.2, OUT3.15, R34.2, R38.2, U13.1, U13.3, U13.4, U13.19, U13.37, U13.43, U13.46, U16.5
3.3V4: C107.1, C108.1, C109.1, C110.1, C111.1, C113.1, C121.1, C125.1, D5.VCC, IN4.2, IN4.15, OUT4.2, OUT4.15, R45.2, R49.2, U17.1, U17.3, U17.4, U17.19, U17.37, U17.43, U17.46, U20.5
3.3V5: C132.1, C133.1, C134.1, C135.1, C136.1, C138.1, C146.1, C150.1, D6.VCC, IN5.2, IN5.15, OUT5.2, OUT5.15, R56.2, R60.2, U21.1, U21.3, U21.4, U21.19, U21.37, U21.43, U21.46, U24.5
3.3V6: C157.1, C158.1, C159.1, C160.1, C161.1, C163.1, C171.1, C175.1, D7.VCC, IN6.2, IN6.15, OUT6.2, OUT6.15, R67.2, R71.2, U25.1, U25.3, U25.4, U25.19, U25.37, U25.43, U25.46, U28.5
3.3V7: C182.1, C183.1, C184.1, C185.1, C186.1, C188.1, C196.1, C200.1, D8.VCC, IN7.2, IN7.15, OUT7.2, OUT7.15, R78.2, R82.2, U29.1, U29.3, U29.4, U29.19, U29.37, U29.43, U29.46, U32.5
3.3V8: C207.1, C208.1, C209.1, C210.1, C211.1, C213.1, C221.1, C225.1, D9.VCC, IN8.2, IN8.15, OUT8.2, OUT8.15, R89.2, R93.2, U33.1, U33.3, U33.4, U33.19, U33.37, U33.43, U33.46, U36.5
3.3V9: C232.1, C233.1, C234.1, C235.1, C236.1, C238.1, C246.1, C250.1, D10.VCC, IN9.2, IN9.15, OUT9.2, OUT9.15, R100.2, R104.2, U37.1, U37.3, U37.4, U37.19, U37.37, U37.43, U37.46, U40.5
3.3V10: C257.1, C258.1, C259.1, C260.1, C261.1, C263.1, C271.1, C275.1, D11.VCC, IN10.2, IN10.15, OUT10.2, OUT10.15, R111.2, R115.2, U41.1, U41.3, U41.4, U41.19, U41.37, U41.43, U41.46, U44.5
3.3V11: C282.1, C283.1, C284.1, C285.1, C286.1, C288.1, C296.1, C300.1, D12.VCC, IN11.2, IN11.15, OUT11.2, OUT11.15, R122.2, R126.2, U45.1, U45.3, U45.4, U45.19, U45.37, U45.43, U45.46, U48.5
3.3V12: C307.1, C308.1, C309.1, C310.1, C311.1, C313.1, C321.1, C325.1, D13.VCC, IN12.2, IN12.15, OUT12.2, OUT12.15, R133.2, R137.2, U49.1, U49.3, U49.4, U49.19, U49.37, U49.43, U49.46, U52.5
3.3V13: C332.1, C333.1, C334.1, C335.1, C336.1, C338.1, C346.1, C350.1, D14.VCC, IN13.2, IN13.15, OUT13.2, OUT13.15, R144.2, R148.2, U53.1, U53.3, U53.4, U53.19, U53.37, U53.43, U53.46, U56.5
3.3V14: C357.1, C358.1, C359.1, C360.1, C361.1, C363.1, C371.1, C375.1, D15.VCC, IN14.2, IN14.15, OUT14.2, OUT14.15, R155.2, R159.2, U57.1, U57.3, U57.4, U57.19, U57.37, U57.43, U57.46, U60.5
3.3V15: C382.1, C383.1, C384.1, C385.1, C386.1, C388.1, C396.1, C400.1, D16.VCC, IN15.2, IN15.15, OUT15.2, OUT15.15, R166.2, R170.2, U61.1, U61.3, U61.4, U61.19, U61.37, U61.43, U61.46, U64.5
3.3V16: C407.1, C408.1, C409.1, C410.1, C411.1, C413.1, C421.1, C425.1, D17.VCC, IN16.2, IN16.15, OUT16.2, OUT16.15, R177.2, R181.2, U65.1, U65.3, U65.4, U65.19, U65.37, U65.43, U65.46, U68.5
3.3V17: C432.1, C433.1, C434.1, C435.1, C436.1, C438.1, C446.1, C450.1, D18.VCC, IN17.2, IN17.15, OUT17.2, OUT17.15, R188.2, R192.2, U69.1, U69.3, U69.4, U69.19, U69.37, U69.43, U69.46, U72.5
3.3V18: C457.1, C458.1, C459.1, C460.1, C461.1, C463.1, C471.1, C475.1, D19.VCC, IN18.2, IN18.15, OUT18.2, OUT18.15, R199.2, R203.2, U73.1, U73.3, U73.4, U73.19, U73.37, U73.43, U73.46, U76.5
3.3V19: C482.1, C483.1, C484.1, C485.1, C486.1, C488.1, C496.1, C500.1, D20.VCC, IN19.2, IN19.15, OUT19.2, OUT19.15, R210.2, R214.2, U77.1, U77.3, U77.4, U77.19, U77.37, U77.43, U77.46, U80.5
3.3V20: C507.1, C508.1, C509.1, C510.1, C511.1, C513.1, C521.1, C525.1, D21.VCC, IN20.2, IN20.15, OUT20.2, OUT20.15, R221.2, R225.2, U81.1, U81.3, U81.4, U81.19, U81.37, U81.43, U81.46, U84.5
3.3V21: C532.1, C533.1, C534.1, C535.1, C536.1, C538.1, C546.1, C550.1, D22.VCC, IN21.2, IN21.15, OUT21.2, OUT21.15, R232.2, R236.2, U85.1, U85.3, U85.4, U85.19, U85.37, U85.43, U85.46, U88.5
3.3V22: C557.1, C558.1, C559.1, C560.1, C561.1, C563.1, C571.1, C575.1, D23.VCC, IN22.2, IN22.15, OUT22.2, OUT22.15, R243.2, R247.2, U89.1, U89.3, U89.4, U89.19, U89.37, U89.43, U89.46, U92.5
3.3V23: C582.1, C583.1, C584.1, C585.1, C586.1, C588.1, C596.1, C600.1, D24.VCC, IN23.2, IN23.15, OUT23.2, OUT23.15, R254.2, R258.2, U93.1, U93.3, U93.4, U93.19, U93.37, U93.43, U93.46, U96.5
3.3V24: C607.1, C608.1, C609.1, C610.1, C611.1, C613.1, C621.1, C625.1, D25.VCC, IN24.2, IN24.15, OUT24.2, OUT24.15, R265.2, R269.2, U97.1, U97.3, U97.4, U97.19, U97.37, U97.43, U97.46, U100.5
3.3V25: C632.1, C633.1, C634.1, C635.1, C636.1, C638.1, C646.1, C650.1, D26.VCC, IN25.2, IN25.15, OUT25.2, OUT25.15, R276.2, R280.2, U101.1, U101.3, U101.4, U101.19, U101.37, U101.43, U101.46, U104.5
3.3V26: C657.1, C658.1, C659.1, C660.1, C661.1, C663.1, C671.1, C675.1, D27.VCC, IN26.2, IN26.15, OUT26.2, OUT26.15, R287.2, R291.2, U105.1, U105.3, U105.4, U105.19, U105.37, U105.43, U105.46, U108.5
3.3V27: C682.1, C683.1, C684.1, C685.1, C686.1, C688.1, C696.1, C700.1, D28.VCC, IN27.2, IN27.15, OUT27.2, OUT27.15, R298.2, R302.2, U109.1, U109.3, U109.4, U109.19, U109.37, U109.43, U109.46, U112.5
3.3V28: C707.1, C708.1, C709.1, C710.1, C711.1, C713.1, C721.1, C725.1, D29.VCC, IN28.2, IN28.15, OUT28.2, OUT28.15, R309.2, R313.2, U113.1, U113.3, U113.4, U113.19, U113.37, U113.43, U113.46, U116.5
3.3V29: C732.1, C733.1, C734.1, C735.1, C736.1, C738.1, C746.1, C750.1, D30.VCC, IN29.2, IN29.15, OUT29.2, OUT29.15, R320.2, R324.2, U117.1, U117.3, U117.4, U117.19, U117.37, U117.43, U117.46, U120.5
3.3V30: C757.1, C758.1, C759.1, C760.1, C761.1, C763.1, C771.1, C775.1, D31.VCC, IN30.2, IN30.15, OUT30.2, OUT30.15, R331.2, R335.2, U121.1, U121.3, U121.4, U121.19, U121.37, U121.43, U121.46, U124.5
3.3V31: C782.1, C783.1, C784.1, C785.1, C786.1, C788.1, C796.1, C800.1, D32.VCC, IN31.2, IN31.15, OUT31.2, OUT31.15, R342.2, R346.2, U125.1, U125.3, U125.4, U125.19, U125.37, U125.43, U125.46, U128.5
4: C28.2, U5.5
5: C28.1, U5.6
6: C10.1, U2.6
7: C54.1, U9.7
8: C53.2, U9.5
9: C53.1, U9.6
10: C79.1, U13.7
11: C78.2, U13.5
12: C78.1, U13.6
13: C104.1, U17.7
14: C103.2, U17.5
15: C103.1, U17.6
16: C129.1, U21.7
17: C128.2, U21.5
18: C128.1, U21.6
19: C154.1, U25.7
20: C153.2, U25.5
21: C153.1, U25.6
22: C179.1, U29.7
23: C178.2, U29.5
24: C178.1, U29.6
25: C204.1, U33.7
26: C203.2, U33.5
27: C203.1, U33.6
28: C229.1, U37.7
29: C228.2, U37.5
30: C228.1, U37.6
31: C254.1, U41.7
32: C253.2, U41.5
32-RTC: C3.2, U2.12, X1.P$1
32-RTC1: C39.2, U5.12, X4.P$1
32-RTC2: C64.2, U9.12, X6.P$1
32-RTC3: C89.2, U13.12, X8.P$1
32-RTC4: C114.2, U17.12, X10.P$1
32-RTC5: C139.2, U21.12, X12.P$1
32-RTC6: C164.2, U25.12, X14.P$1
32-RTC7: C189.2, U29.12, X16.P$1
32-RTC8: C214.2, U33.12, X18.P$1
32-RTC9: C239.2, U37.12, X20.P$1
32-RTC10: C264.2, U41.12, X22.P$1
32-RTC11: C289.2, U45.12, X24.P$1
32-RTC12: C314.2, U49.12, X26.P$1
32-RTC13: C339.2, U53.12, X28.P$1
32-RTC14: C364.2, U57.12, X30.P$1
32-RTC15: C389.2, U61.12, X32.P$1
32-RTC16: C414.2, U65.12, X34.P$1
32-RTC17: C439.2, U69.12, X36.P$1
32-RTC18: C464.2, U73.12, X38.P$1
32-RTC19: C489.2, U77.12, X40.P$1
32-RTC20: C514.2, U81.12, X42.P$1
32-RTC21: C539.2, U85.12, X44.P$1
32-RTC22: C564.2, U89.12, X46.P$1
32-RTC23: C589.2, U93.12, X48.P$1
32-RTC24: C614.2, U97.12, X50.P$1
32-RTC25: C639.2, U101.12, X52.P$1
32-RTC26: C664.2, U105.12, X54.P$1
32-RTC27: C689.2, U109.12, X56.P$1
32-RTC28: C714.2, U113.12, X58.P$1
32-RTC29: C739.2, U117.12, X60.P$1
32-RTC30: C764.2, U121.12, X62.P$1
32-RTC31: C789.2, U125.12, X64.P$1
33: C253.1, U41.6
33-RTC: C4.2, U2.13, X1.P$2
33-RTC1: C40.2, U5.13, X4.P$2
33-RTC2: C65.2, U9.13, X6.P$2
33-RTC3: C90.2, U13.13, X8.P$2
33-RTC4: C115.2, U17.13, X10.P$2
33-RTC5: C140.2, U21.13, X12.P$2
33-RTC6: C165.2, U25.13, X14.P$2
33-RTC7: C190.2, U29.13, X16.P$2
33-RTC8: C215.2, U33.13, X18.P$2
33-RTC9: C240.2, U37.13, X20.P$2
33-RTC10: C265.2, U41.13, X22.P$2
33-RTC11: C290.2, U45.13, X24.P$2
33-RTC12: C315.2, U49.13, X26.P$2
33-RTC13: C340.2, U53.13, X28.P$2
33-RTC14: C365.2, U57.13, X30.P$2
33-RTC15: C390.2, U61.13, X32.P$2
33-RTC16: C415.2, U65.13, X34.P$2
33-RTC17: C440.2, U69.13, X36.P$2
33-RTC18: C465.2, U73.13, X38.P$2
33-RTC19: C490.2, U77.13, X40.P$2
33-RTC20: C515.2, U81.13, X42.P$2
33-RTC21: C540.2, U85.13, X44.P$2
33-RTC22: C565.2, U89.13, X46.P$2
33-RTC23: C590.2, U93.13, X48.P$2
33-RTC24: C615.2, U97.13, X50.P$2
33-RTC25: C640.2, U101.13, X52.P$2
33-RTC26: C665.2, U105.13, X54.P$2
33-RTC27: C690.2, U109.13, X56.P$2
33-RTC28: C715.2, U113.13, X58.P$2
33-RTC29: C740.2, U117.13, X60.P$2
33-RTC30: C765.2, U121.13, X62.P$2
33-RTC31: C790.2, U125.13, X64.P$2
34: C279.1, U45.7
35: C278.2, U45.5
36: C278.1, U45.6
37: C304.1, U49.7
38: C303.2, U49.5
39: C303.1, U49.6
40: C329.1, U53.7
41: C328.2, U53.5
42: C328.1, U53.6
43: C354.1, U57.7
44: C353.2, U57.5
45: C353.1, U57.6
46: C379.1, U61.7
47: C378.2, U61.5
48: C378.1, U61.6
49: C404.1, U65.7
50: C403.2, U65.5
51: C403.1, U65.6
52: C429.1, U69.7
53: C428.2, U69.5
54: C428.1, U69.6
55: C454.1, U73.7
56: C453.2, U73.5
57: C453.1, U73.6
58: C479.1, U77.7
59: C478.2, U77.5
60: C478.1, U77.6
61: C504.1, U81.7
62: C503.2, U81.5
63: C503.1, U81.6
64: C529.1, U85.7
65: C528.2, U85.5
66: C528.1, U85.6
67: C554.1, U89.7
68: C553.2, U89.5
69: C553.1, U89.6
70: C579.1, U93.7
71: C578.2, U93.5
72: C578.1, U93.6
73: C604.1, U97.7
74: C603.2, U97.5
75: C603.1, U97.6
76: C629.1, U101.7
77: C628.2, U101.5
78: C628.1, U101.6
79: C654.1, U105.7
80: C653.2, U105.5
81: C653.1, U105.6
82: C679.1, U109.7
83: C678.2, U109.5
84: C678.1, U109.6
85: C704.1, U113.7
86: C703.2, U113.5
87: C703.1, U113.6
88: C729.1, U117.7
89: C728.2, U117.5
90: C728.1, U117.6
91: C754.1, U121.7
92: C753.2, U121.5
93: C753.1, U121.6
94: C779.1, U125.7
95: C778.2, U125.5
96: C778.1, U125.6
!RESET: !RESET!.1, Q1.3, R2.1, U2.9
!RESET1: !RESET!1.1, Q2.3, R12.1, U5.9
!RESET2: !RESET!2.1, Q3.3, R23.1, U9.9
!RESET3: !RESET!3.1, Q4.3, R34.1, U13.9
!RESET4: !RESET!4.1, Q5.3, R45.1, U17.9
!RESET5: !RESET!5.1, Q6.3, R56.1, U21.9
!RESET6: !RESET!6.1, Q7.3, R67.1, U25.9
!RESET7: !RESET!7.1, Q8.3, R78.1, U29.9
!RESET8: !RESET!8.1, Q9.3, R89.1, U33.9
!RESET9: !RESET!9.1, Q10.3, R100.1, U37.9
!RESET10: !RESET!10.1, Q11.3, R111.1, U41.9
!RESET11: !RESET!11.1, Q12.3, R122.1, U45.9
!RESET12: !RESET!12.1, Q13.3, R133.1, U49.9
!RESET13: !RESET!13.1, Q14.3, R144.1, U53.9
!RESET14: !RESET!14.1, Q15.3, R155.1, U57.9
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

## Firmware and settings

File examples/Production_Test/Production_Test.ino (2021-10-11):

// smôl ESP32 Production Test
//
// Written by Paul Clark (PaulZC)
// October 11th, 2021
//
// Select SparkFun ESP32 Thing as the board
//
// Make sure you have the correct drivers installed for the Silicon Labs
// CP210x USB to UART Bridge otherwise the automatic upload may fail
// https://www.silabs.com/developers/usb-to-uart-bridge-vcp-drivers
//
// This is the code we use to test the board during production:
//   The WiFi is checked - the board will report how many networks are available
//   The LED will cycle through Red-Green-Blue, changing every second
//   The GPIO pins used by smôl are read periodically
//   Serial messages are generated and are read by the production test jig
//   The jig will toggle the GPIO pins and look for the correct response in the serial messages
//   The serial messages are sent at 115200 baud:
//     "WIFI:n" indicates how many WiFi networks have been found
//     "GPIO:nnnnnnnnnn" indicates the state of the GPIO pins
//       n will be "0" or "1" showing whether the pin is LOW or HIGH
//       The pin order is:
//         SCLK (GPIO18)
//         COPI (GPIO23)
//         CIPO (GPIO19)
//         CS0 (GPIO5)
//         CS1 (GPIO14)
//         CS2 (GPIO13)
//         GPIO0 (GPIO27)
//         GPIO1 (GPIO26)
//         SDA (GPIO21)
//         SCL (GPIO22)

// Drive the LED using FastLED
#include <FastLED.h> // http://librarymanager/All#FastLED
#define LED_PIN     25 //GPIO25 on smôl ESP32 is connected to WS2812 LED
#define COLOR_ORDER GRB
#define CHIPSET     WS2812
#define NUM_LEDS    1
#define BRIGHTNESS  50
CRGB leds[NUM_LEDS];
unsigned int RGBarray[] = {CRGB::Red, CRGB::Green, CRGB::Blue};
volatile uint8_t rgbStep = 0;

// The GPIO pins
const uint8_t numPins = 10;
const uint8_t thePins[numPins] = {18, 23, 19, 5, 14, 13, 27, 26, 21, 22 };

//WiFi
#include <WiFi.h>

//Globals
byte numNetworks = 0;

//Ticker for LED updates
#include <Ticker.h>
Ticker toggler;
void toggle()
{
  leds[0] = RGBarray[rgbStep]; // Cycle through RGB
  FastLED.show();
  rgbStep = (rgbStep + 1) % 3;
}

void setup() {
  delay(1000);

  Serial.begin(115200);
  Serial.println(F("SparkFun smôl ESP32 Production Test"));

  //Set up the LED
  FastLED.addLeds<CHIPSET, LED_PIN, COLOR_ORDER>(leds, NUM_LEDS).setCorrection( TypicalLEDStrip );
  FastLED.setBrightness( BRIGHTNESS );
  leds[0] = CRGB::White;
  FastLED.show();

  //Set all the GPIO pins to INPUT
  for (uint8_t i = 0; i < numPins; i++)
    pinMode(thePins[i], INPUT);

  //Test WiFi - report how many WiFi networks can be seen
  numNetworks = WiFi.scanNetworks();

  //Toggle the LED color now that SPIFFS and WiFi tests are complete
  toggler.attach(1.0, toggle); // Toggle the LED every second
}

void loop()
{
  Serial.print(F("WIFI:"));
  Serial.println(numNetworks);

  //Read the GPIO pins
  Serial.print(F("GPIO:"));
  for (uint8_t i = 0; i < numPins; i++)
  {
    if (digitalRead(thePins[i]) == HIGH)
      Serial.print(F("1"));
    else
      Serial.print(F("0"));
  }
  Serial.println();

  delay(50);
}

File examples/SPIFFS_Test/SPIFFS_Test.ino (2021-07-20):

// smôl ESP32 SPIFFS Test
//
// Select SparkFun ESP32 Thing as the board
//
// Make sure you have the correct drivers installed for the Silicon Labs
// CP210x USB to UART Bridge otherwise the automatic upload may fail
// https://www.silabs.com/developers/usb-to-uart-bridge-vcp-drivers

#include "FS.h"
#include "SPIFFS.h"

/* You only need to format SPIFFS the first time you run a
   test or else use the SPIFFS plugin to create a partition
   https://github.com/me-no-dev/arduino-esp32fs-plugin */
#define FORMAT_SPIFFS_IF_FAILED true

void listDir(fs::FS &fs, const char * dirname, uint8_t levels){
    Serial.printf("Listing directory: %s\r\n", dirname);

    File root = fs.open(dirname);
    if(!root){
        Serial.println("- failed to open directory");
        return;
    }
    if(!root.isDirectory()){
        Serial.println(" - not a directory");
        return;
    }

    File file = root.openNextFile();
    while(file){
        if(file.isDirectory()){
            Serial.print("  DIR : ");
            Serial.println(file.name());
            if(levels){
                listDir(fs, file.name(), levels -1);
            }
        } else {
            Serial.print("  FILE: ");
            Serial.print(file.name());
            Serial.print("\tSIZE: ");
            Serial.println(file.size());
        }
        file = root.openNextFile();
    }
}

void readFile(fs::FS &fs, const char * path){
    Serial.printf("Reading file: %s\r\n", path);

    File file = fs.open(path);
    if(!file || file.isDirectory()){
        Serial.println("- failed to open file for reading");
        return;
    }

    Serial.println("- read from file:");
    while(file.available()){
        Serial.write(file.read());
    }
    file.close();
}

void writeFile(fs::FS &fs, const char * path, const char * message){
    Serial.printf("Writing file: %s\r\n", path);

    File file = fs.open(path, FILE_WRITE);
    if(!file){
        Serial.println("- failed to open file for writing");
        return;
    }
    if(file.print(message)){
        Serial.println("- file written");
    } else {
        Serial.println("- write failed");
    }
    file.close();
}

void appendFile(fs::FS &fs, const char * path, const char * message){
    Serial.printf("Appending to file: %s\r\n", path);

    File file = fs.open(path, FILE_APPEND);
    if(!file){
        Serial.println("- failed to open file for appending");
        return;
    }
    if(file.print(message)){
        Serial.println("- message appended");
    } else {
        Serial.println("- append failed");
    }
    file.close();
}

void renameFile(fs::FS &fs, const char * path1, const char * path2){
    Serial.printf("Renaming file %s to %s\r\n", path1, path2);
    if (fs.rename(path1, path2)) {
        Serial.println("- file renamed");
    } else {
        Serial.println("- rename failed");
    }
}

void deleteFile(fs::FS &fs, const char * path){
    Serial.printf("Deleting file: %s\r\n", path);
    if(fs.remove(path)){
        Serial.println("- file deleted");
    } else {
        Serial.println("- delete failed");
    }
}

void testFileIO(fs::FS &fs, const char * path){
    Serial.printf("Testing file I/O with %s\r\n", path);

    static uint8_t buf[512];
    size_t len = 0;
    File file = fs.open(path, FILE_WRITE);
    if(!file){
        Serial.println("- failed to open file for writing");
        return;
    }

    size_t i;
    Serial.print("- writing" );
    uint32_t start = millis();
    for(i=0; i<2048; i++){
        if ((i & 0x001F) == 0x001F){
          Serial.print(".");
        }
        file.write(buf, 512);
    }
    Serial.println("");
    uint32_t end = millis() - start;
    Serial.printf(" - %u bytes written in %u ms\r\n", 2048 * 512, end);
    file.close();

    file = fs.open(path);
    start = millis();
    end = start;
    i = 0;
    if(file && !file.isDirectory()){
        len = file.size();
        size_t flen = len;
        start = millis();
        Serial.print("- reading" );
        while(len){
            size_t toRead = len;
            if(toRead > 512){
                toRead = 512;
            }
            file.read(buf, toRead);
            if ((i++ & 0x001F) == 0x001F){
              Serial.print(".");
            }
            len -= toRead;
        }
        Serial.println("");
        end = millis() - start;
        Serial.printf("- %u bytes read in %u ms\r\n", flen, end);
        file.close();
    } else {
        Serial.println("- failed to open file for reading");
    }
}

void setup(){
    Serial.begin(115200);

    Serial.println(F("SparkFun smôl ESP32 SPIFFS Test"));
    
    if(!SPIFFS.begin(FORMAT_SPIFFS_IF_FAILED)){
        Serial.println(F("SPIFFS Mount Failed"));
        return;
    }
    
    listDir(SPIFFS, "/", 0);
    writeFile(SPIFFS, "/hello.txt", "Hello ");
    appendFile(SPIFFS, "/hello.txt", "World!\r\n");
    readFile(SPIFFS, "/hello.txt");
    renameFile(SPIFFS, "/hello.txt", "/foo.txt");
    readFile(SPIFFS, "/foo.txt");
    listDir(SPIFFS, "/", 0);
    deleteFile(SPIFFS, "/foo.txt");
    listDir(SPIFFS, "/", 0);
    testFileIO(SPIFFS, "/test.txt");
    listDir(SPIFFS, "/", 0);
    deleteFile(SPIFFS, "/test.txt");
    listDir(SPIFFS, "/", 0);
    Serial.println( "Test complete" );
}

void loop(){

}

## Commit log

2021-05-11 Work in progress
    [SparkX_EZ_ESP32.brd, SparkX_EZ_ESP32.sch]
2021-05-11 Add CP2102 package outline
    [SparkX_EZ_ESP32.brd, SparkX_EZ_ESP32.sch]
2021-05-12 Ready for review
    [SparkX_EZ_ESP32.brd]
2021-05-13 Add neopixel. Add mirror-symmetric production panel
    [SparkX_EZ_ESP32-Panel.GBL, SparkX_EZ_ESP32-Panel.GBO, SparkX_EZ_ESP32-Panel.GBP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]
2021-05-14 Post-review updates
    [SparkX_EZ_ESP32-Panel.brd, SparkX_EZ_ESP32.brd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]
2021-05-27 Gapless production panel
    [SparkX_EZ_ESP32-Panel.brd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]
2021-06-09 Updates for JLCPCB manufacture
    [SparkX_EZ_ESP32-Panel.brd, SparkX_EZ_ESP32.brd]
2021-06-09 Update 16-way FPC Connector
    [SparkX_EZ_ESP32.brd, SparkX_EZ_ESP32.sch]
2021-08-20 X02 - add smôl branding
    [SparkX_EZ_ESP32-Panel.brd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]
2021-10-10 Auto-detect COM port. Use LED to show when SPIFFS and WiFi tests are complete

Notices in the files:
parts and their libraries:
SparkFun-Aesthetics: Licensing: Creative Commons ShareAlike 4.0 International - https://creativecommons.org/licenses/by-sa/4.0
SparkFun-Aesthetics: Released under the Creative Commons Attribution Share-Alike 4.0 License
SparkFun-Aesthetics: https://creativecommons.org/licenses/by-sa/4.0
